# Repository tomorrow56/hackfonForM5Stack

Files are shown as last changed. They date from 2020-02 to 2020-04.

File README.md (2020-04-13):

# hackfonForM5Stack

「hackfon」とは「アナログ電話をスマートリモコンに」というコンセプトで「FutuRocket株式会社」 (https://www.futurocket.co/) が現在製品化に向けて進めているIoTプロダクトです。

hackfon

以下に簡単な製品説明があります。<br>
(技術書典#8の"Madamada M5Stack Moku Moku Mook β" ( https://booth.pm/ja/items/1887481 )からの抜粋版です)<br>

/techbookfesta8/tomorrow56_tech8_03.md

### 2020年4月13日更新

"exsample"にIFTTT対応版を追加しました。<br>

#### /example/M5_hackfon_IFTTT

同梱の "hackfon.cfg" を編集して "makerKey"と"Event trigger"を設定に応じて書き換えてSDカードのルートに置けば設定をこちらから読みますので、ソースを修正する必要はありません。今回のバージョンでは各キーに１つのIFTTTのイベントキーが割り当てることができます。<br><br>

また、コンパイル済のバイナリー(M5-SD-Updater対応版, M5_hackfon_IFTTT.bin) も準備しました。<br>
こちらをSDカードのルートに置いて、以下のM5Burnerをダウンロードして、LovyanLauncher-v0.2.3 を本体に書き込めばSDカードに保存したバイナリーを実行することができます。<br>
https://m5stack.oss-cn-shenzhen.aliyuncs.com/resource/software/M5Burner.zip

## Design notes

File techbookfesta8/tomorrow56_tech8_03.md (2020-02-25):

---
title: hackfon for M5Stackの紹介
tags: M5Stack FutuRocket hackfon
author: tomorrow56 (ThousanDIY)
slide: false
---

# 開発中のhackfon for M5Stack の紹介

「hackfon」とは「アナログ電話をスマートリモコンに」というコンセプトで「FutuRocket株式会社」 (https://www.futurocket.co/) が現在製品化に向けて進めているIoTプロダクトです。

hackfon

**hackfonのリーフレット**

筆者は「FutuRocket様」に許可をもらい、M5Stack版である「hackfon for M5Stack」の設計を進めていますので、簡単に紹介します。

## hackfonとは
「hackdon」は「Yahoo! JAPAN HackDay 2017」でHack賞を受賞した「アナログ固定電話機をWi-Fi接続しIoT/ウェブサービスのリモートコントローラーに変えるデバイス」です。
電話機のプッシュボタンを押すだけでデジタル家電やIoTデバイス、ウェブサービスをコントロールできるようになります。
「hackfon」はESP32ベースのデバイスで電源と電話機を接続するだけのシンプルな構成となっています。

## 「hackfon for M5Stack」の概要
オリジナルの「hackfon」は 10cm x 10cm で接続状態はLEDで表示します。また、Wi-Fiへの接続設定は内蔵しているWebブラウザ経由で行います。
これを「M5Stack用のモジュール」の形にすることで、M5Stackの液晶ディスプレイを利用した各種状態やコマンドの表示や、SDカードを使ったデータ保存に対応することができます。
以下は、今回に試作した「hackfon for M5Stack」です。接続した電話機のキーの検出して画面に表示しています。

hackfon For M5Stack

**hackfon For M5Stack**

## オリジナルのhackfon との違い

M5Stackのモジュールサイズである 5cm x 5cm に収めるために以下の機能変更を行っています。

### 電話線用コネクタ(RJ11)の削減

オリジナルでは通常の電話機としても使用できるように電話線用のコネクタ(RJ11)を2個搭載し、リレーで切り替えを行っていますが、M5Stack版ではコネクタは1個になっています。これにより電話の公衆回線には繋げられなくなります。これにより「端末機器に関する基準認証制度」の適用除外になるというメリットもあります。

RJ11コネクタ部

**RJ11コネクタは1個のみ搭載**

### 内蔵レギュレータの削除

オリジナルではACアダプタ入力(12～15V、電話機の電源に使用)から内部回路用の5V及び3.3Vを生成していたのですが、M5Stack版では電源をM5StackのM-BUSから供給するようにしました。また、モジュールが厚くなるので、M5Stackのボトムモジュール(バッテリー内蔵)を使うことが難しくなります。そのため、本モジュールにLiPoバッテリーを直接接続できるようなコネクタを追加しました。また、メカニカルスイッチによりLiPoバッテリーをOFFできるようにしています。これによりM5Stackの弱点である「電源OFF時の内蔵バッテリーの放電」を改善することができます。

これらの変更を行うことにより、M5Stackのモジュール内にhackfonの機能をすべて実装することができました。以下が実装後の基板になります。下の方に見える青い2ピンのコネクタはLiPoバッテリー接続端子です。

M5Stack版の実装済基板

**M5Stack版の実装済基板**

## 今後の展開について

現時点(2020年2月)ではM5Stack版は基本回路構成が固まって動作確認まで出来た段階です。
実際の製造開始までには、ハードウエアでは「中国での部品の調達性に応じた回路の見直し」「内蔵用のLiPoバッテリーの安全な固定方法」「ケースの設計・調達方法」、ソフトウエアでは「サービス連携をどうするか」「LCDによるユーザーインターフェースの設計」等、まだいくつもの課題があります。どのような形で販売するかも含めて引き続き検討していきます。

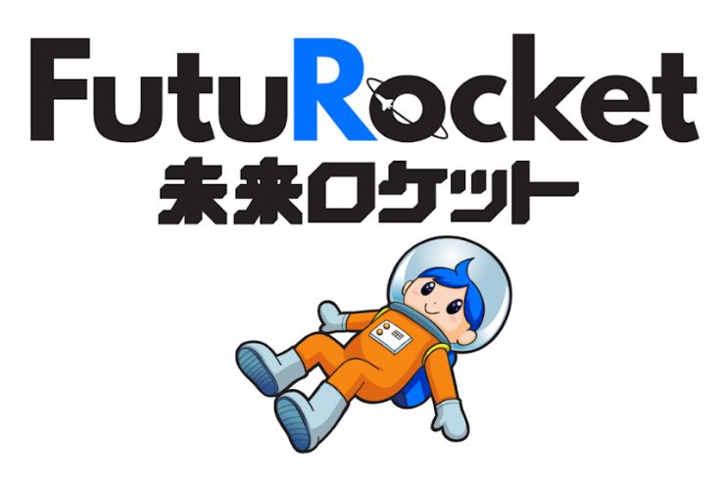
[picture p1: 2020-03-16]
example/M5_hackfon_v01/Futurocket.JPG

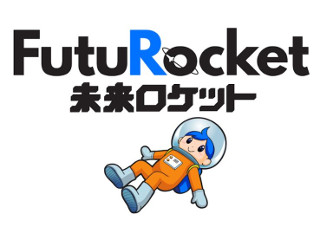
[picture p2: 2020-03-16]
example/M5_hackfon_v01/Futurocket_mini.JPG

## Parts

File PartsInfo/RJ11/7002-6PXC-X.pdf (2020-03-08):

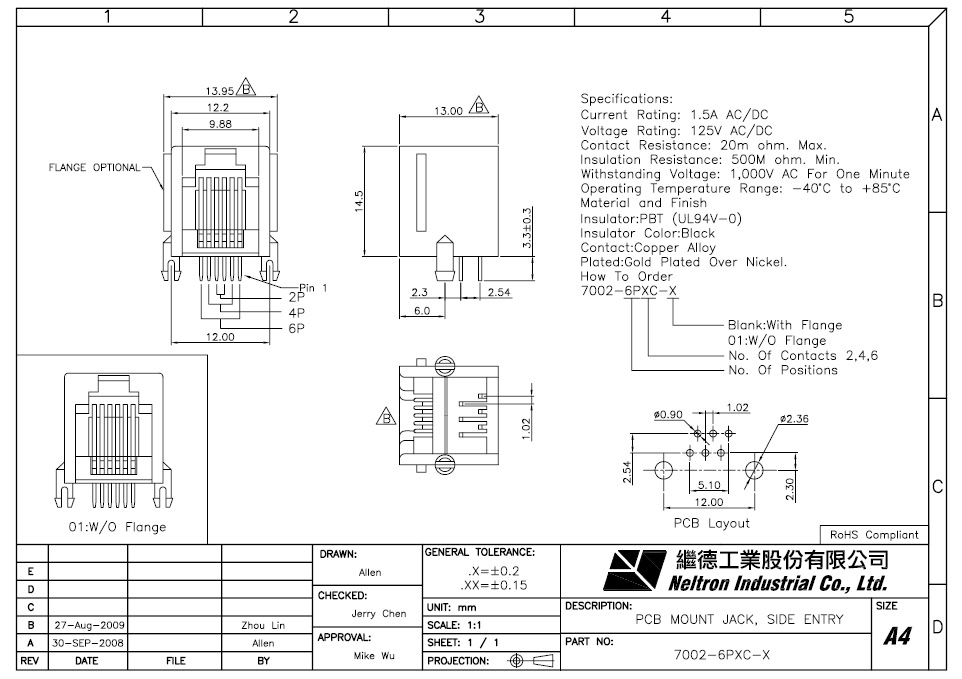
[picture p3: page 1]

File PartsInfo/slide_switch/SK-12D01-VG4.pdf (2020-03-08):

# [参考資料]

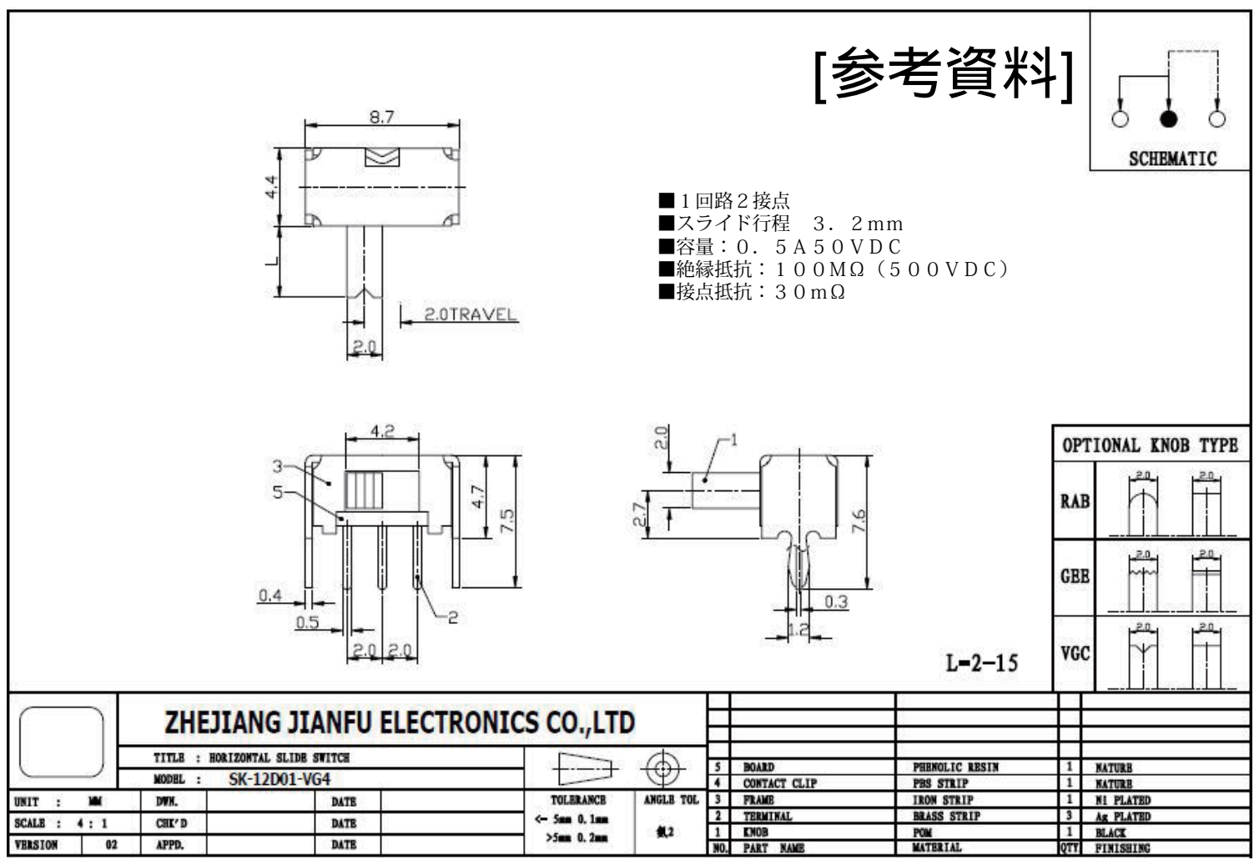
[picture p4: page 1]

■１回路２接点
■スライド行程　３．２ｍｍ
■容量：０．５Ａ５０ＶＤＣ
■絶縁抵抗：１００ＭΩ（５００ＶＤＣ）
■接点抵抗：３０ｍΩ

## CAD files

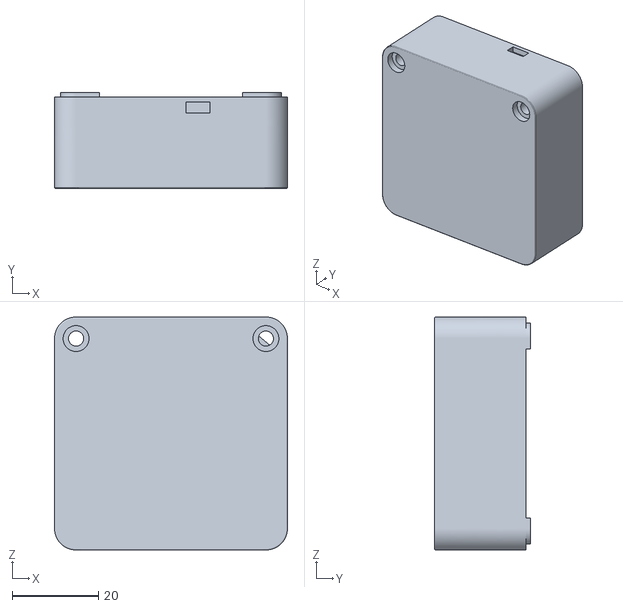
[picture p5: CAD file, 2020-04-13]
case/hackfon_case_0.7mm v2.stl
54.0 x 22.2 x 54.0

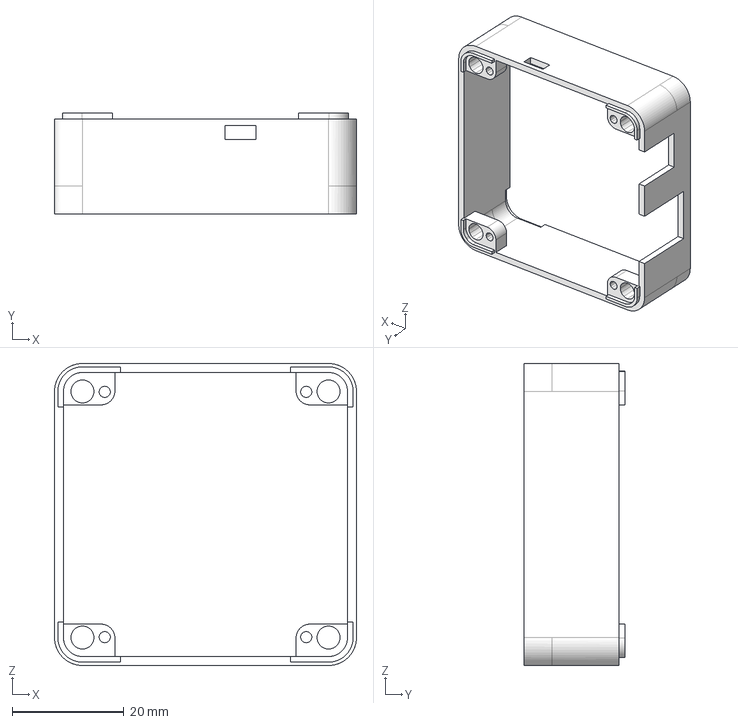
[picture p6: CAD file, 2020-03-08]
case/tentative/M5Hackfon_v02_case.step
54.0 x 18.0 x 54.0 mm

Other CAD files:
case/tentative/M5Hackfon_v02_case.f3d
case/tentative/M5Hackfon_v02_case.stl

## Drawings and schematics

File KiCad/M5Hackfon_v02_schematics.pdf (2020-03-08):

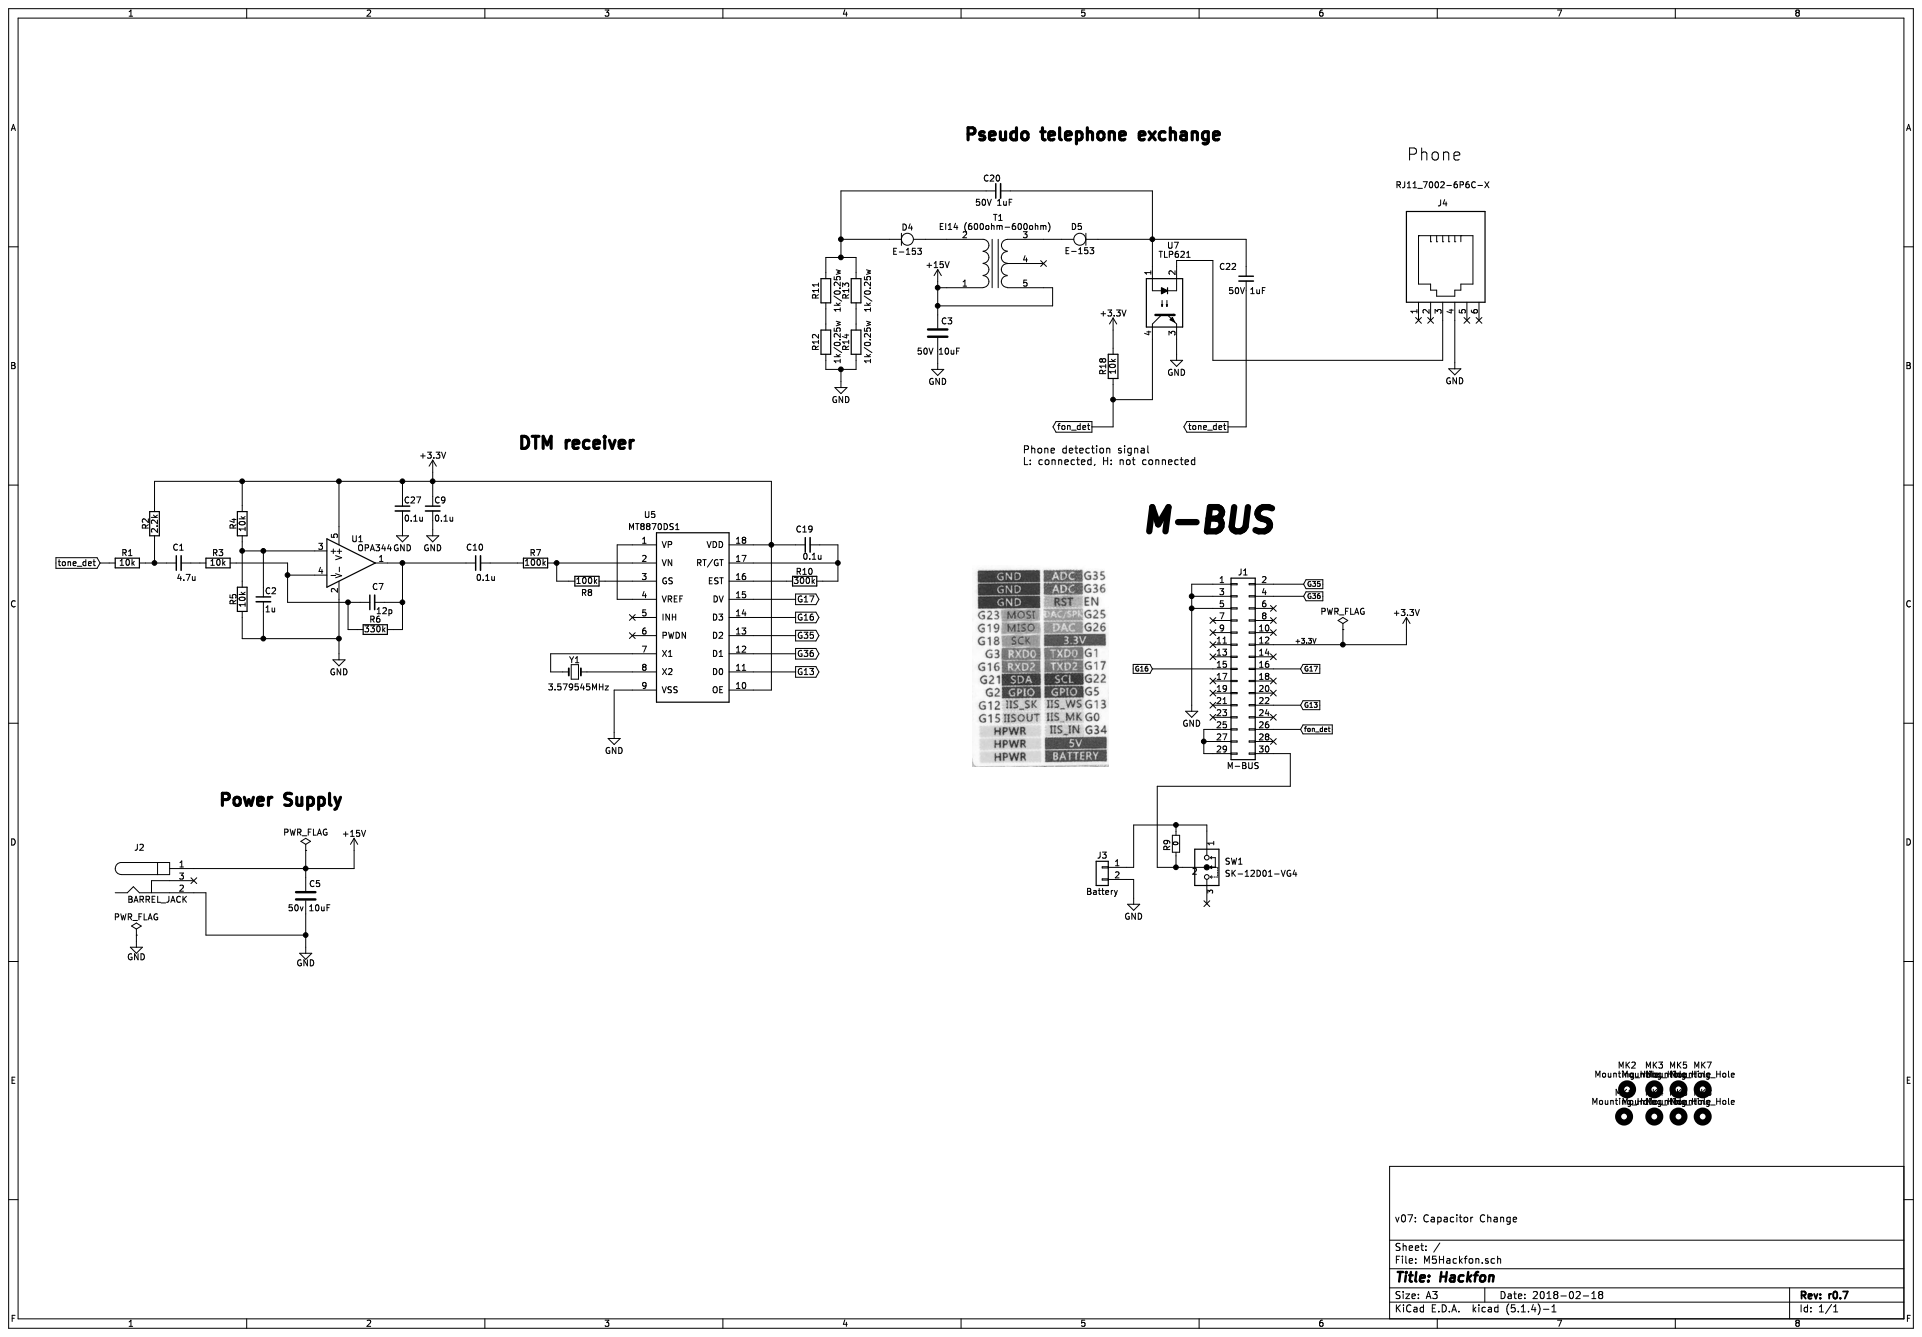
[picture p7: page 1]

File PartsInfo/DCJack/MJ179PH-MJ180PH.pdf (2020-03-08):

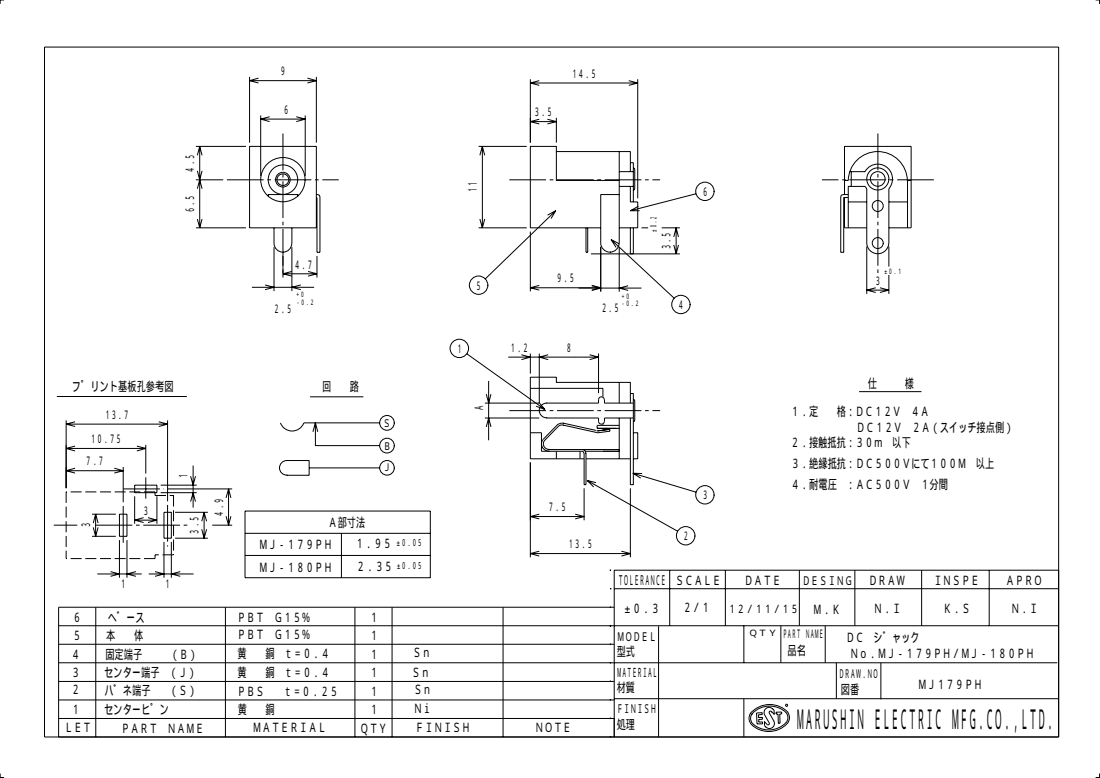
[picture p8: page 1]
ＭＯＤＥＬ; ＦＩＮＩＳＨ; ＬＥＴ; ＰＡＲＴ ＮＡＭＥ; ＭＡＴＥＲＩＡＬ; ＱＴＹ; ＮＯＴＥ; センターヒ゜ン; ハ゛ネ端子 （Ｓ）; センター端子 （Ｊ）; 固定端子 （Ｂ）; ＰＢＳ ｔ＝０．２５; ＰＢＴ Ｇ１５％; φＡ部寸法; フ゜リント基板孔参考図; ２．接触抵抗：３０ｍΩ以下; ３．絶縁抵抗：ＤＣ５００Ｖにて１００ＭΩ以上; ４．耐電圧 ：ＡＣ５００Ｖ １分間; ＤＣ１２Ｖ ２Ａ（スイッチ接点側）

ＭＪ－１７９ＰＨ | φ１．９５ ±０．０５
ＭＪ－１８０ＰＨ | φ２．３５ ±０．０５

ＴＯＬＥＲＡＮＣＥ | ＳＣＡＬＥ | ＤＡＴＥ ＤＥＳＩＮＧ ＤＲＡＷ ＩＮＳＰＥ | ＡＰＲＯ

ＱＴＹ ＰＡＲＴ　ＮＡＭＥ

ＤＣ　シ゛ャック

ＭＡＴＥＲＩＡＬ 材質 | ＤＲＡＷ．ＮＯ ＭＪ１７９ＰＨ 図番

ＭＡＲＵＳＨＩＮ　ＥＬＥＣＴＲＩＣ　ＭＦＧ．ＣＯ．，ＬＴＤ．

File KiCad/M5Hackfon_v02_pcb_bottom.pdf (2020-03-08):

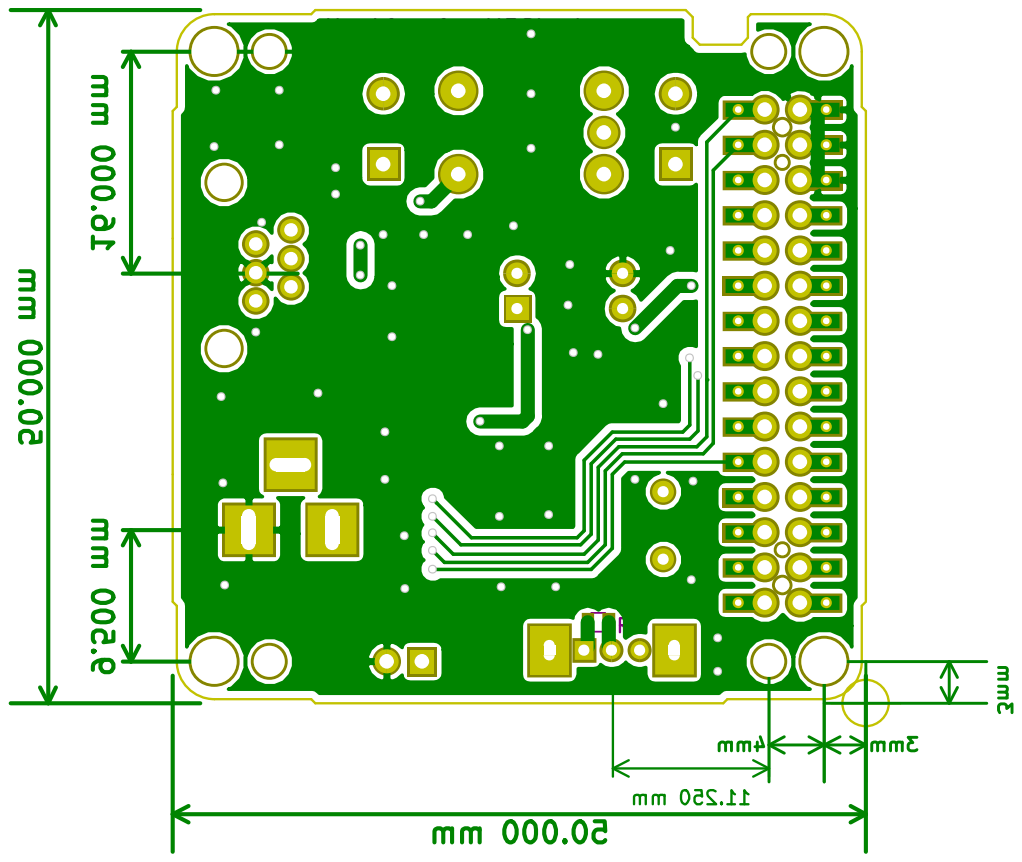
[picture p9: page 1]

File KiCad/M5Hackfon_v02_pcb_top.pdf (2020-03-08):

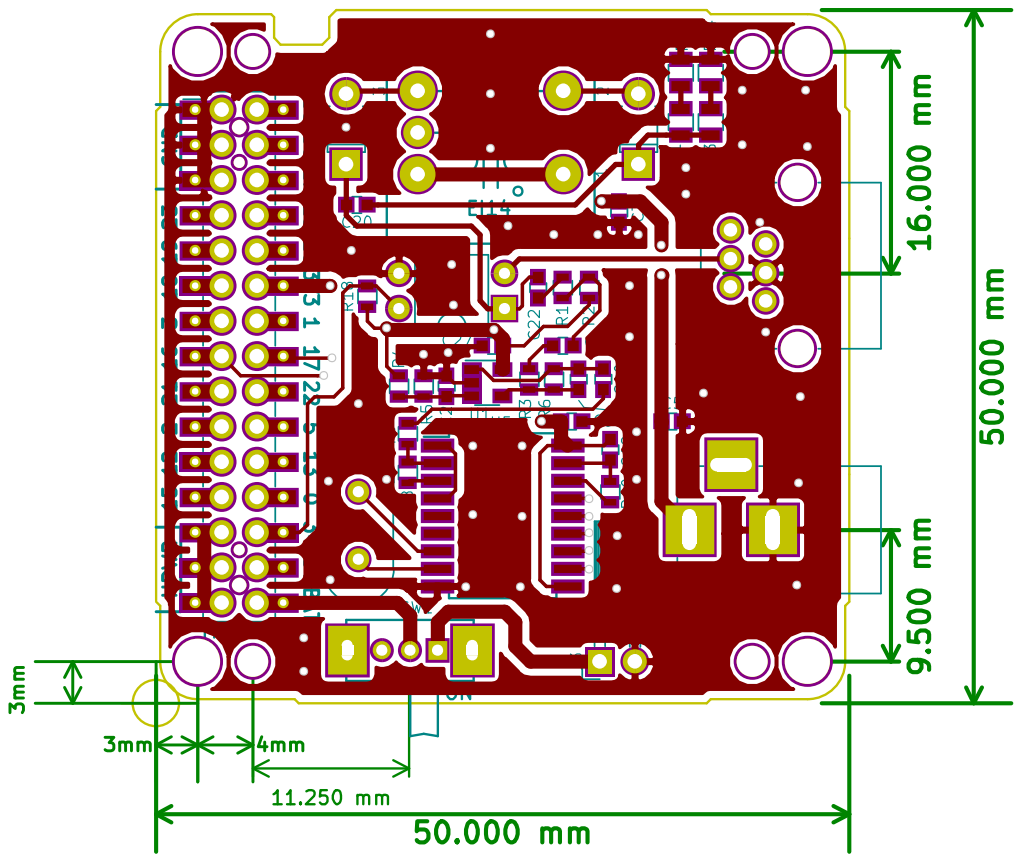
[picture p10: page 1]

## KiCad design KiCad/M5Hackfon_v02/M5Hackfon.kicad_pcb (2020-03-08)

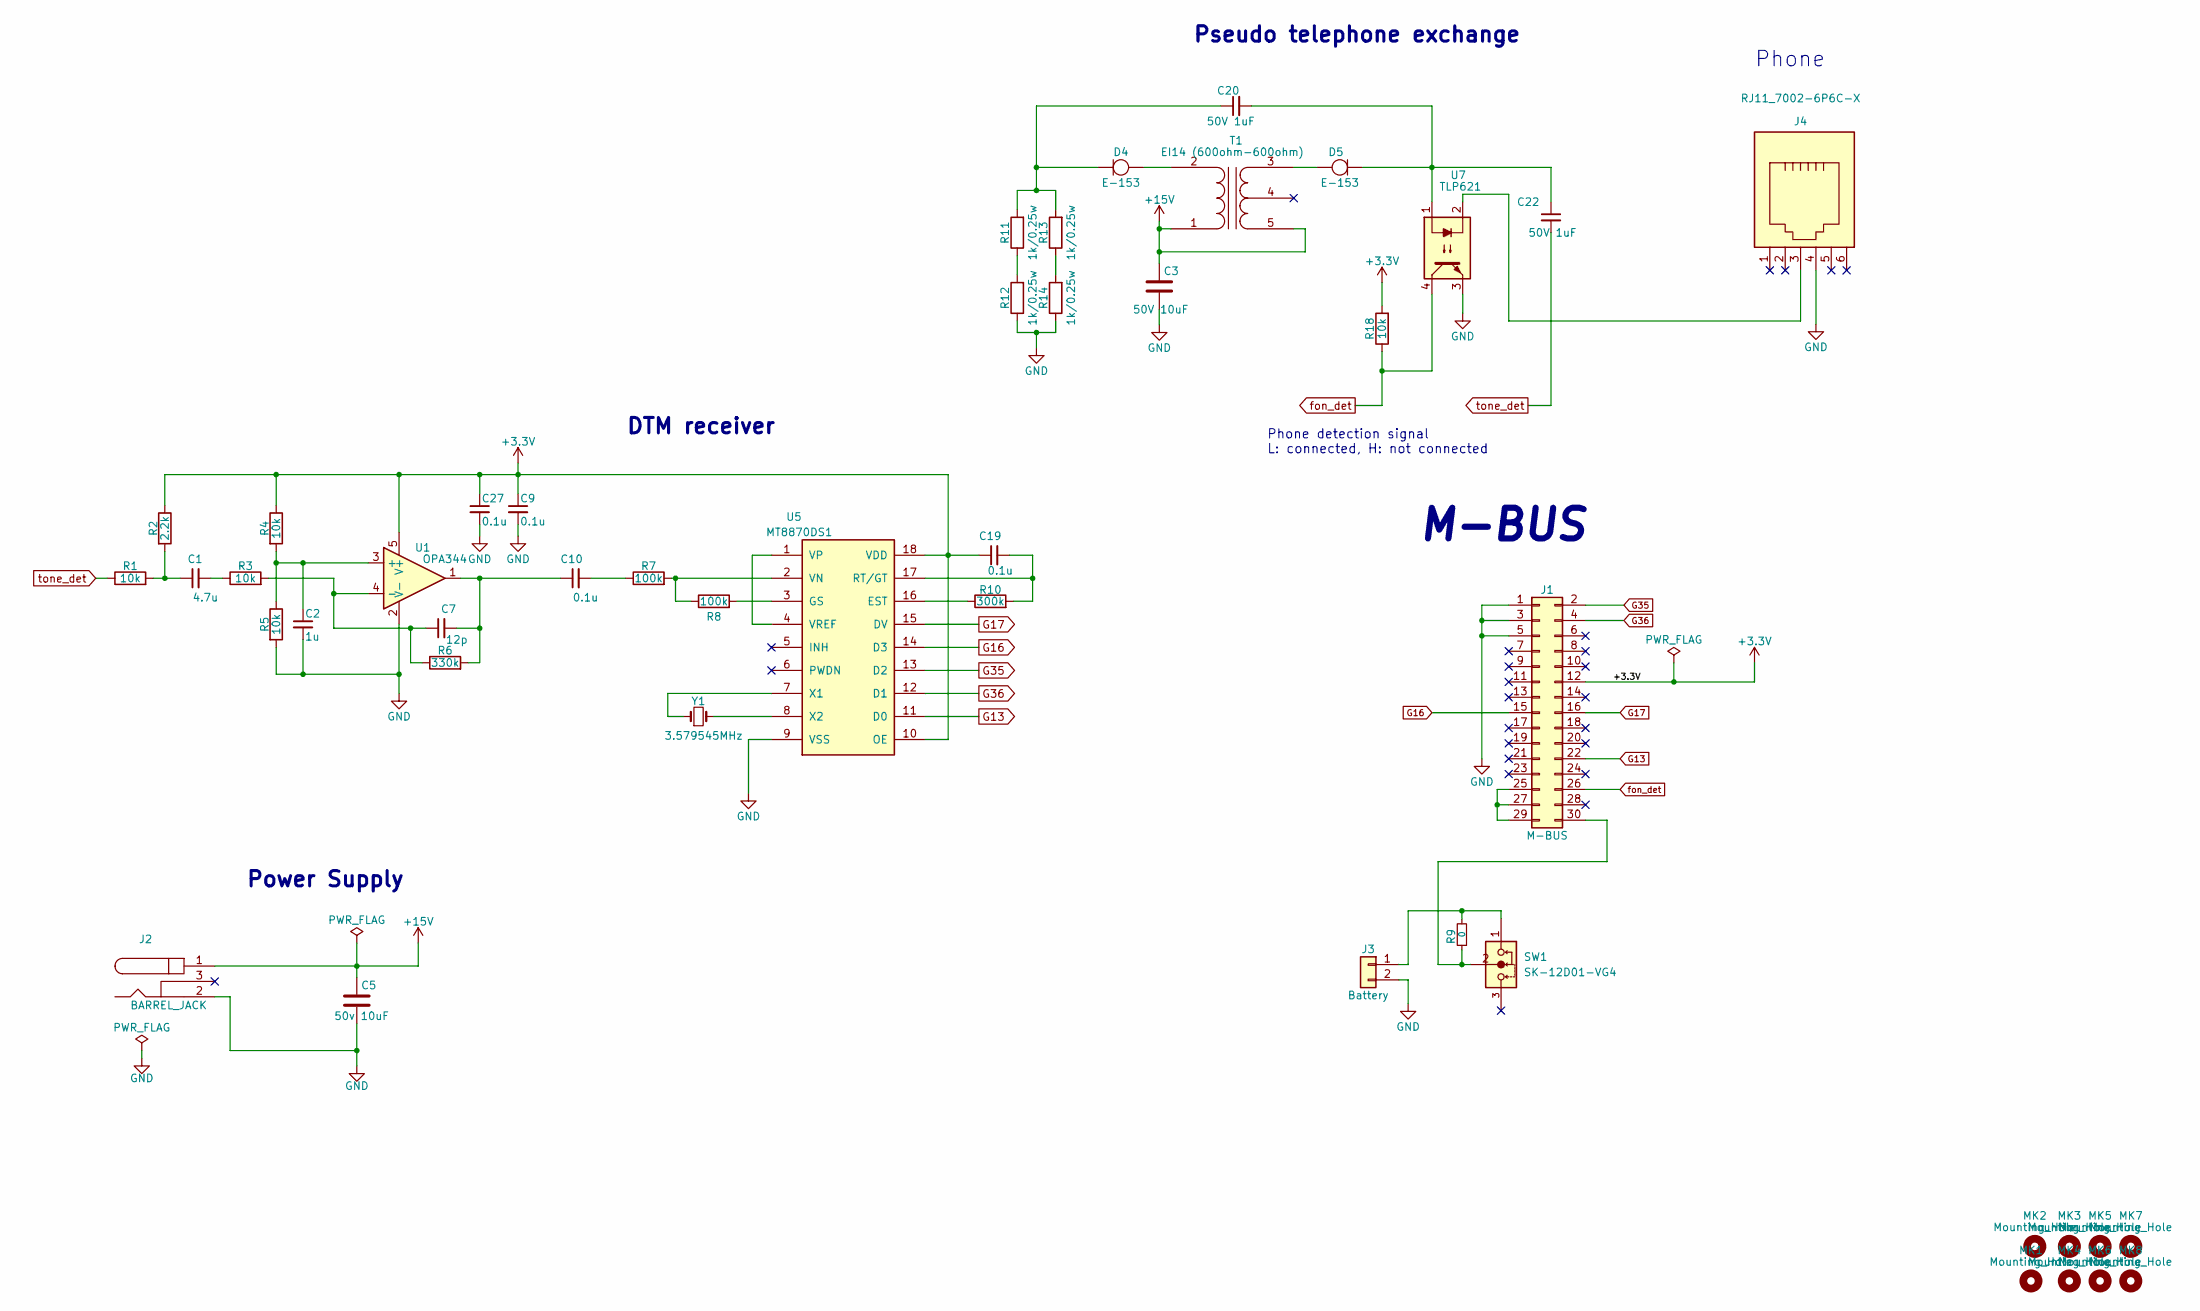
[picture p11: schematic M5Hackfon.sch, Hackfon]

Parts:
C1: 4.7u; C_0603
C2: 1u; C_0603
C3: 50V 10uF; C_0603
C5: 50v 10uF; C_0603
C7: 12p; C_0603
C9, C10, C19, C27: 0.1u; C_0603
C20, C22: 50V 1uF; C_0603
D4, D5: E-153; D_T-1_P5.08mm_Horizontal
J1: M-BUS; Pin_Header_MBUS_SMD_TH
J2: BARREL_JACK
J3: Battery; Pin_Header_Angled_1x02_Pitch2.54mm
J4: RJ11_7002-6P6C-X
MK1, MK2, MK3, MK4: Mounting_Hole; MountingHole_3.2mm_M3
MK5, MK6, MK7, MK8: Mounting_Hole; MountingHole_2.2mm_M2
R1, R3, R4, R5, R18: 10k; R_0603
R2: 2.2k; R_0603
R6: 330k; R_0603
R7, R8: 100k; R_0603
R9: 0; R_0603
R10: 300k; R_0603
R11, R12, R13, R14: 1k/0.25w; R_0805
SW1: SK-12D01-VG4; slide_switch_angled
T1: EI14 (600ohm-600ohm); TRANS_EI14
U1: OPA344; SOT-23-5
U5: MT8870DS1; SOIC-18W_7.5x11.6mm_Pitch1.27mm
U7: TLP621; DIP-4_W7.62mm
Y1: 3.579545MHz; Crystal_HC49-U_Vertical

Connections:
+3V3: C9.1, C19.1, C27.1, J1.12, R2.1, R4.1, R18.2, U1.5 (V+), U5.10 (OE), U5.18 (VDD)
+15V: C3.1, C5.1, J2.1, T1.1 (AA), T1.5 (SB)
G13: J1.22, U5.11 (D0)
G16: J1.15, U5.14 (D3)
G17: J1.16, U5.15 (DV)
G35: J1.2, U5.13 (D2)
G36: J1.4, U5.12 (D1)
GND: C2.2, C3.2, C5.2, C9.2, C27.2, J1.1, J1.3, J1.5, J2.2, J3.2, J4.4, R5.2, R12.1, R14.1, U1.2 (V-), U5.9 (VSS), U7.3
unnamed: C1.1, R1.2, R2.2
unnamed: C1.2, R3.1
unnamed: C2.1, R4.2, R5.1, U1.3 (+)
unnamed: C7.1, R3.2, R6.1, U1.4 (-)
unnamed: C7.2, C10.1, R6.2, U1.1
unnamed: C10.2, R7.1
unnamed: C19.2, R10.2, U5.17 (RT/GT)
unnamed: C20.1, D4.1 (K), R11.2, R13.2
unnamed: C20.2, C22.1, D5.1 (K), U7.1
unnamed: D4.2 (A), T1.2 (AB)
unnamed: D5.2 (A), T1.3 (SA)
unnamed: J1.25, J1.27, J1.29
unnamed: J1.30, R9.1, SW1.2
unnamed: J3.1, R9.2, SW1.1
unnamed: J4.3, U7.2
unnamed: R7.2, R8.1, U5.2 (VN)
unnamed: R8.2, U5.3 (GS)
unnamed: R10.1, U5.16 (EST)
unnamed: R11.1, R12.2
unnamed: R13.1, R14.2
unnamed: U5.1 (VP), U5.4 (VREF)
unnamed: U5.7 (X1), Y1.1
unnamed: U5.8 (X2), Y1.2
fon_det: J1.26, R18.1, U7.4
tone_det: C22.2, R1.1

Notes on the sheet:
Power Supply
Phone
Pseudo telephone exchange
Phone detection signal L: connected, H: not connected
DTM receiver
M-BUS

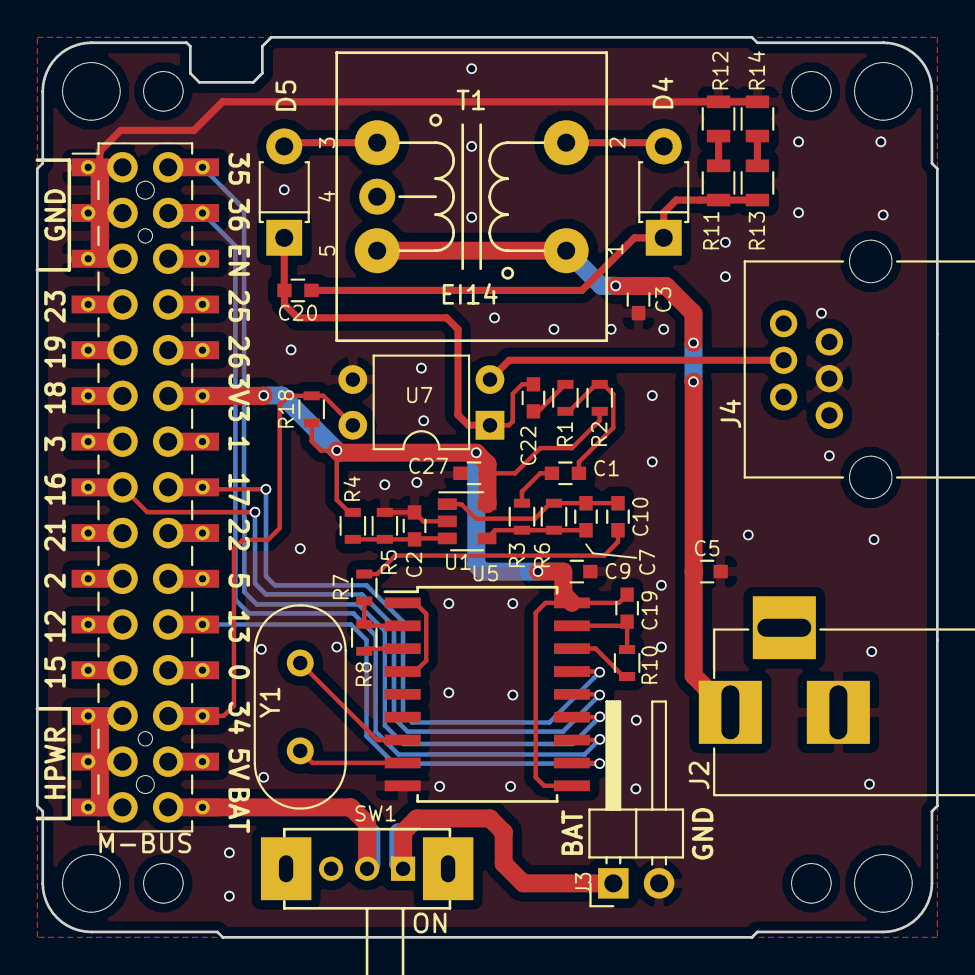
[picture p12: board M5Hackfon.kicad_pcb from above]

Board: 2 copper layers, 50.0 x 50.0 mm, 46 parts (1 on the bottom side), 33 nets.

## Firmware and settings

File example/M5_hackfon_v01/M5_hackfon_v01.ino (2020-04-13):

/***************************************************
 * Hackfon for M5Stack
 * by Team GENPEI
 *
 * 2019/02/02
 * Customized for M5Stack by ThousanDIY
****************************************************/
#include "ArduinoJson.h"

#include <M5Stack.h>
#include "M5StackUpdater.h"

#include <WiFi.h>
// #include <Time.h>        // http://playground.arduino.cc/Code/time
#include <TimeLib.h>        // https://forum.arduino.cc/index.php?topic=415296.0
#include <DNSServer.h>      // https://github.com/zhouhan0126/DNSServer---esp32
#include <WebServer.h>      // https://github.com/zhouhan0126/WebServer-esp32
#include "WiFiManager.h"   // https://github.com/zhouhan0126/WIFIMANAGER-ESP32

// Use Hackfon Logo
extern const unsigned char gImage_logoFR[];

// Interrupt Pin for dial detection
#define INTPIN 17

// Data pin  for dial detection
const int DPIN[4] = {13, 36, 35, 16};

#define onhookPin 34   // the number of the pushbutton pin

// コマンドバッファ
uint8_t command_buffer[10] = {};
uint8_t received_length = 0;
boolean command_mode = false;

const uint8_t COMMANDMAXLEN = 10;

// GENPEI WebAPI設定
const char* DEST_HOST = "192.168.11.108";
const uint16_t DEST_PORT = 80;
const char* DEST_URL = "/hue/api.php?command=";

// レスポンス用バッファ
const int BUFFER_SIZE = JSON_OBJECT_SIZE(100) + JSON_ARRAY_SIZE(100);
StaticJsonBuffer<BUFFER_SIZE> jsonBuffer;

// 状態保持用変数
uint8_t last_code;
unsigned long last_time = 0;
boolean send_flag = false;
boolean onhook_flag = true;

// WiFi系インスタンス
WiFiManager wifiManager;
WiFiClient client;

/*
 * バッファオーバーフローエラーの処理
 */
void bof_error (void) {
  Serial.print("BOF error: ");
  for (uint8_t i = 0; i < COMMANDMAXLEN; i++) {
      Serial.print(command_buffer[i]);
  }
  Serial.println("");
  received_length = 0;
  command_mode = false;
}

/*
 * コマンドを送信する
 */
void send_command (void) {
  String line;
  String url;
  if (received_length > 0) {
    // URLの生成と受信コマンドの表示
    url = String(DEST_URL);
    Serial.print("command: ");
    for (uint8_t i = 0; i < received_length; i++) {
      url += command_buffer[i];
      Serial.print(command_buffer[i]);
    }
    Serial.println("");
    // 送信フラグを戻す
    send_flag = false;
    // バッファの初期化
    received_length = 0;
    command_mode = false;

    if (!client.connect(DEST_HOST, DEST_PORT)) {
      // 送信のための接続に失敗した時
      Serial.println("connection failed");
      return;
    }

    client.print(String("GET ") + url + String(" HTTP/1.1\r\n") +
      String("Host: ") + String(DEST_HOST) + String("\r\n") +
      String("Connection: close\r\n\r\n"));
    delay(500);

//    //get rid of the HTTP headers
//    while(client.available()){
//      line = client.readStringUntil('\r');
//      Serial.print(line);
//      line.trim();
//      if (line.length() == 0) {
//        break;
//      }
//    }
//
//    //get http content
//    String buffer="";
//    while(client.available()){
//      line = client.readStringUntil('\r');
//      line.trim();
//      buffer.concat(line);
//    }
client.stop();
    //parse json data
//    char json[buffer.length() + 1];
//    buffer.toCharArray(json, sizeof(json));
//    Serial.println(json);
//    JsonObject& root = jsonBuffer.parseObject(json);
//    if (!root.success()) {
//      Serial.println("parseObject() failed");
//      return;
//    }

    Serial.println("closing connection");
    Serial.println("");
  }
}

/*
 * DTMFレシーバからデータ取り込み
 */
void readDtmfData() {
  uint8_t code = 0;
  unsigned long time;
  for (uint8_t i = 0; i < 4; i++) {
    code += (digitalRead(DPIN[i]) << i);
  }

  time = millis();
  if (time - last_time < 200) {
    last_time = time;
    if (last_code == code) {
      last_code = code;
      return;
    }
  }
  last_time = time;
  last_code = code;

  M5.Lcd.setTextColor(TFT_GREEN, TFT_BLACK);

  // コマンドの認識
  switch (code) {
    case 1:
    case 2:
    case 3:
    case 4:
    case 5:
    case 6:
    case 7:
    case 8:
    case 9:
    case 10:
      if (command_mode && !send_flag) {
        if (received_length >COMMANDMAXLEN) {
          send_command();
          bof_error();
        } else {
          command_buffer[received_length] = code % 10;
          received_length++;
          if (received_length == 4) {
            send_flag = true;
          }
        }
      }
      break;
    case 11:
      Serial.println("command start");
      M5.Lcd.setTextSize(3);
      M5.Lcd.setCursor(40, 80);
      M5.Lcd.print("             ");
      M5.Lcd.setCursor(40, 80);
      M5.Lcd.print("command start");

//      digitalWrite(ledOnline, true);
      received_length = 0;
      command_mode = true;
      break;
    case 12:
      send_command();
      send_flag = true;
      break;
  }
  Serial.println(code);
  M5.Lcd.setTextSize(4);
  M5.Lcd.setCursor(140, 120);
  M5.Lcd.print("  ");
  M5.Lcd.setCursor(140, 120);
  M5.Lcd.print(code);
}

void setup() {
  String line;
  String url;

  // TFT_BL OFF
  pinMode(32, OUTPUT);
  digitalWrite(32, LOW);

  M5.begin();

  if(digitalRead(BUTTON_A_PIN) == 0) {
    Serial.println("Will Load menu binary");
//    updateFromFS(SD, fileInfo[ M5Menu.getListID() ].fileName);
    updateFromFS(SD);
    ESP.restart();
  }

  M5.Lcd.fillScreen(BLACK);
  M5.Lcd.setBrightness(0);

  delay(200);

  // FutuRocket Logo
  M5.Lcd.pushImage(0, 0, 320, 240, (uint16_t *)gImage_logoFR);

  for(int i = 0; i <= 127; i++){
    M5.Lcd.setBrightness(i);
    delay(20);
  }

  delay(1000);

  for(int i = 127; i >= 0; i--){
    M5.Lcd.setBrightness(i);
    delay(10);
  }

  M5.Lcd.fillScreen(BLACK);
  delay(500);
  M5.Lcd.setBrightness(127);

  Serial.println("Hackfone for M5Stack");
  Serial.println("");

  M5.Lcd.setCursor(0, 0);
  M5.Lcd.setTextColor(WHITE);
  M5.Lcd.setTextSize(2);

  M5.Lcd.println("Hackfone by team GENPEI");
  M5.Lcd.println("");
  M5.Lcd.println(" AP name: HackfonConfigAP");
  M5.Lcd.println(" IP adrs: 192.168.4.1");

  // Display QRCode
  M5.Lcd.qrcode("http://192.168.4.1", 150, 70, 150, 6);

  // WiFiManagerのデバッグ用メッセージ表示
  wifiManager.setDebugOutput(true);

  // WiFiManagerによる接続（接続できない場合はHackfonConfigAPというAPが立ち上がる）
  wifiManager.autoConnect("HackfonConfigAP");

   //if you get here you have connected to the WiFi
  IPAddress ipadr = WiFi.localIP();
  Serial.println("connected!");
  Serial.println(WiFi.SSID());
  Serial.println(ipadr);

  M5.Lcd.fillScreen(TFT_BLACK);
  M5.Lcd.setTextColor(GREEN);
  M5.Lcd.setCursor(0, 0);

  M5.Lcd.setTextSize(2);

  M5.Lcd.println("Wifi Connected!");
  M5.Lcd.println("");
  M5.Lcd.println(" SSID: " + WiFi.SSID());
  M5.Lcd.println(" IP adrs: " + (String)ipadr[0] + "." + (String)ipadr[1] + "." + (String)ipadr[2] + "." + (String)ipadr[3]);

  // ピンモード設定
  for (uint8_t i = 0; i < 4; i++) {
    pinMode(DPIN[i], INPUT_PULLUP);      // 入力に設定
  }

  last_time = millis();
  last_code = 0;

  //  attachInterrupt(INTPIN, readDtmfData, RISING);
  attachInterrupt(digitalPinToInterrupt(INTPIN), readDtmfData, RISING);

  // initialize the onhook pin as an input:
  pinMode(onhookPin, INPUT);
}

void loop() {
  if(onhook_flag != !digitalRead(onhookPin)){
    if(onhook_flag == true){
      Serial.println("on-hook");
      M5.Lcd.fillRect(300, 10, 10, 10, TFT_BLACK);
      M5.Lcd.setCursor(40, 80);
      M5.Lcd.print("             ");
      M5.Lcd.setCursor(140, 120);
      M5.Lcd.print("  ");
    }else{
      Serial.println("off-hook");
      M5.Lcd.fillRect(300, 10, 10, 10, TFT_MAGENTA);
    }
    onhook_flag = !digitalRead(onhookPin);
  }
  if (send_flag) {
    noInterrupts();
    Serial.println("send command");

    M5.Lcd.setTextSize(3);
    M5.Lcd.setCursor(40, 80);
    M5.Lcd.print("             ");
    M5.Lcd.setCursor(40, 80);
    M5.Lcd.print("send command");
    send_command();
//    digitalWrite(ledOnline, false);
    send_flag = false;
    interrupts();
  }
  delay(50);
}

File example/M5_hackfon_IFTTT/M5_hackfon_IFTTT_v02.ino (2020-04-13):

/***************************************************
 * Hackfon for M5Stack
 * by Team GENPEI and FutuRocket
 *
 * 2020/05/21
 * Customized for M5Stack by ThousanDIY
****************************************************/
#include <M5Stack.h>
#include "M5StackUpdater.h"

#include <WiFi.h>
// #include <Time.h>        // http://playground.arduino.cc/Code/time
#include <TimeLib.h>        // https://forum.arduino.cc/index.php?topic=415296.0
#include <DNSServer.h>
#include <WebServer.h>
#include "WiFiManager.h"   // https://github.com/zhouhan0126/WIFIMANAGER-ESP32

File myFile;

boolean debug = false;

// IFTTT key and event triggers are  
const char* server = "maker.ifttt.com";  // Server URL
String makerKey = ""; // MakerKey of Webhooks
String makerEvent = ""; // Trigger of Webhooks

String Event[12];
boolean sendFlag[12];

// Use Hackfon Logo
extern const unsigned char gImage_logoFR[];

// Interrupt Pin for dial detection
#define INTPIN 17

// Data pin  for dial detection
const int DPIN[4] = {13, 36, 35, 16};

#define onhookPin 34   // the number of the pushbutton pin

// Valiables for Status
uint8_t last_code;
unsigned long last_time = 0;
boolean send_flag = false;
boolean onhook_flag = true;

// WiFi instanse
WiFiManager wifiManager;
WiFiClient client;
IPAddress ipadr;


// read config from SD
void loadConfig() {
  String readLineDummy[100];
  String readLine = "";
  int i = 0;
  int num;

  // open the file for reading:
  myFile = SD.open("/hackfon.cfg");
  if (myFile) {
   if(debug){
     Serial.println("hackfon.cfg:");
   }

    // read from the file until there's nothing else in it:
    while (myFile.available()) {
      readLine.concat(char(myFile.read()));
      if(readLine.endsWith("\n")){
        readLineDummy[i] = readLine.substring(0, readLine.indexOf("\n", 0) - 1);
        readLine = "";
        i++;
      }
    }
    num = i;
    // close the file:
    myFile.close();
  } else {
    // if the file didn't open, print an error:
    Serial.println("error opening hackfon.cfg");
    M5.Lcd.setTextColor(TFT_RED, TFT_BLACK);
    M5.Lcd.setTextSize(2);
    M5.Lcd.setCursor(10, 25);
    M5.Lcd.print("error opening hackfon.cfg");
  }

  String EventDummy;
  String dataDummy;
  
  for(i = 0; i < num; i++){
    if(readLineDummy[i].length() > 0){
      EventDummy = readLineDummy[i].substring(0, readLineDummy[i].indexOf("=", 0) - 1);
      EventDummy.trim();
      dataDummy = readLineDummy[i].substring(readLineDummy[i].indexOf("=", 0) + 1, readLineDummy[i].length());
      dataDummy.trim();
      if(EventDummy == "makerKey"){
        makerKey = dataDummy;
      }
      if(EventDummy == "Event1"){
        Event[0] = dataDummy;
      }
      if(EventDummy == "Event2"){
        Event[1] = dataDummy;
      }
      if(EventDummy == "Event3"){
        Event[2] = dataDummy;
      }
      if(EventDummy == "Event4"){
        Event[3] = dataDummy;
      }
      if(EventDummy == "Event5"){
        Event[4] = dataDummy;
      }
      if(EventDummy == "Event6"){
        Event[5] = dataDummy;
      }
      if(EventDummy == "Event7"){
        Event[6] = dataDummy;
      }
      if(EventDummy == "Event8"){
        Event[7] = dataDummy;
      }
      if(EventDummy == "Event9"){
        Event[8] = dataDummy;
      }
      if(EventDummy == "Event10"){
        Event[9] = dataDummy;
      }
      if(EventDummy == "Event11"){
        Event[10] = dataDummy;
      }
      if(EventDummy == "Event12"){
        Event[11] = dataDummy;
      }
      if(EventDummy == "send1"){
        if(dataDummy == "true"){
          sendFlag[0] = true;
        }else{
          sendFlag[0] = false;
        }
      }
      if(EventDummy == "send2"){
        if(dataDummy == "true"){
          sendFlag[1] = true;
        }else{
          sendFlag[1] = false;
        }
      }
      if(EventDummy == "send3"){
        if(dataDummy == "true"){
          sendFlag[2] = true;
        }else{
          sendFlag[2] = false;
        }
      }
      if(EventDummy == "send4"){
        if(dataDummy == "true"){
          sendFlag[3] = true;
        }else{
          sendFlag[3] = false;
        }
      }
      if(EventDummy == "send5"){
        if(dataDummy == "true"){
          sendFlag[4] = true;
        }else{
          sendFlag[4] = false;
        }
      }
      if(EventDummy == "send6"){
        if(dataDummy == "true"){
          sendFlag[5] = true;
        }else{
          sendFlag[5] = false;
        }
      }
      if(EventDummy == "send7"){
        if(dataDummy == "true"){
          sendFlag[6] = true;
        }else{
          sendFlag[6] = false;
        }
      }
      if(EventDummy == "send8"){
        if(dataDummy == "true"){
          sendFlag[7] = true;
        }else{
          sendFlag[7] = false;
        }
      }
      if(EventDummy == "send9"){
        if(dataDummy == "true"){
          sendFlag[8] = true;
        }else{
          sendFlag[8] = false;
        }
      }
      if(EventDummy == "send10"){
        if(dataDummy == "true"){
          sendFlag[9] = true;
        }else{
          sendFlag[9] = false;
        }
      }
      if(EventDummy == "send11"){
        if(dataDummy == "true"){
          sendFlag[10] = true;
        }else{
          sendFlag[10] = false;
        }
      }
      if(EventDummy == "send12"){
        if(dataDummy == "true"){
          sendFlag[11] = true;
        }else{
          sendFlag[11] = false;
        }
      }
    }
  }

  if(debug){
    Serial.println("makerKey = " + makerKey);
    for(i = 0; i < 12; i++){
      Serial.println("Event" + String(i + 1) + " = " +Event[i]);
      Serial.println("send" + String(i + 1) + " = " + String(sendFlag[i]));
    }
  }
}
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

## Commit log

2020-02-25 初稿の確認依頼用
2020-02-25 Link修正
2020-03-08 add tentative case data
    [M5Hackfon_v02_case.f3d, M5Hackfon_v02_case.step, M5Hackfon_v02_case.stl]
2020-03-08 add Cad data
    [M5Hackfon.kicad_pcb, M5Hackfon.sch]
2020-03-08 add pcb gerber data
    [M5Hackfon.gbl, M5Hackfon.gbo, M5Hackfon.gbs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]
2020-03-08 add gerber data
    [M5Hackfon.gbl, M5Hackfon.gbo, M5Hackfon.gbs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]
2020-03-16 add sample code
2020-04-13 add case data
    [hackfon_case_0.7mm v2.stl]
2020-04-13 sample sketch for IFTTT v02
    [hackfon.cfg]
2020-04-13 Review the folder structure
    [M5Hackfon.gbl, M5Hackfon.gbo, M5Hackfon.gbs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]
